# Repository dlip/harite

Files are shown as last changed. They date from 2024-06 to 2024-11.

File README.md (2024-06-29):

# Harite 5-way Switch Keyboard

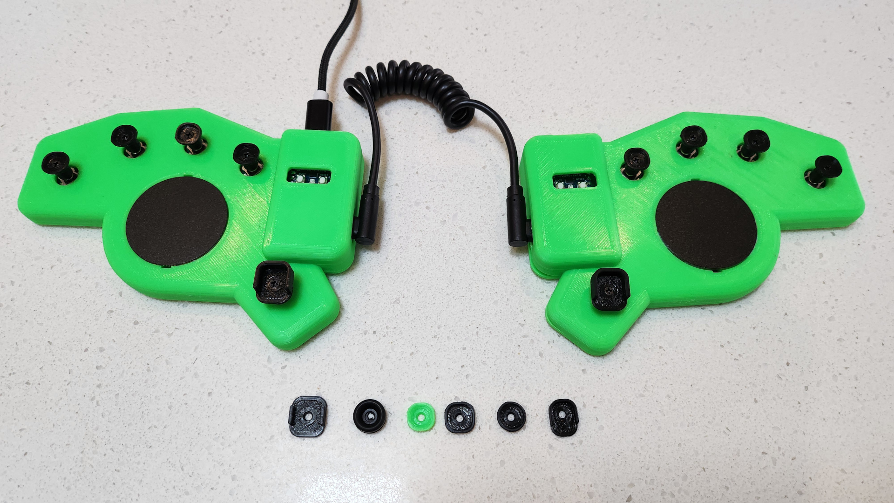
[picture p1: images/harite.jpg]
Harite


- 5-way switches - SKRHADE010 rated at 1,000,000 cycles for each direction
- RP2040-Zero controller
- Split using USB-C to connect the halves
- Dual Cirque 40mm trackpads (optional - you can put a Ploopy or other small trackball in place instead)
- QMK Firmware
- Custom PCB and case
- Hot-swapable joystick caps
- The name comes from the Sumo Slap attack in Japanese
- See a [video demonstration](https://youtu.be/vVsztPqckJc)
- If you would like to make your own, checkout the detailed [build guide](build.md)

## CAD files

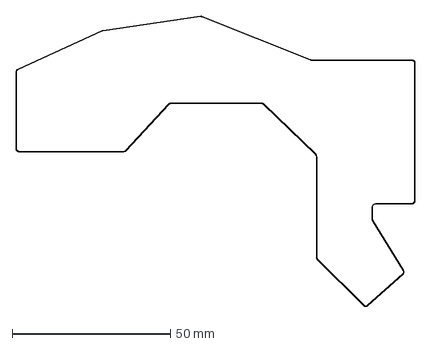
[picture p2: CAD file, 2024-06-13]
design/harite-pcb.dxf
125.9 x 91.7 mm

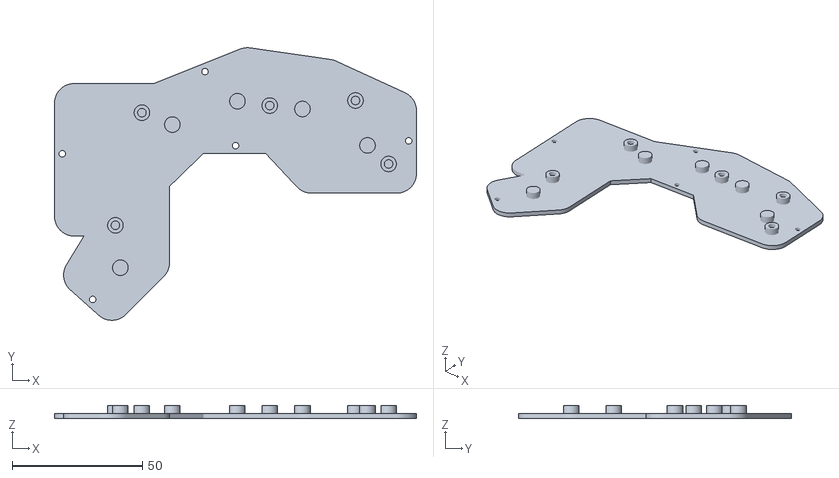
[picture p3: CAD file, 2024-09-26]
printables/Case (no cirque) (untested) - base - right.stl
139.1 x 104.8 x 5.00

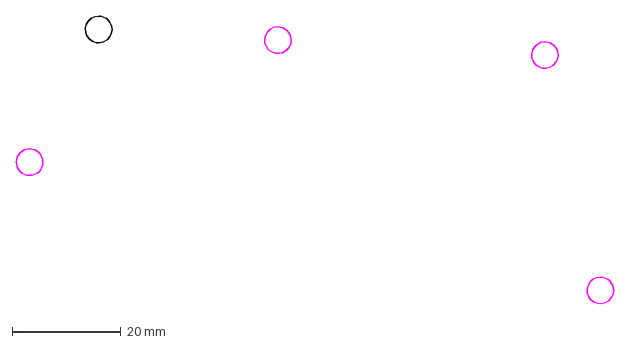
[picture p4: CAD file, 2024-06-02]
design/harite-holes.dxf
109.9 x 53.1 mm

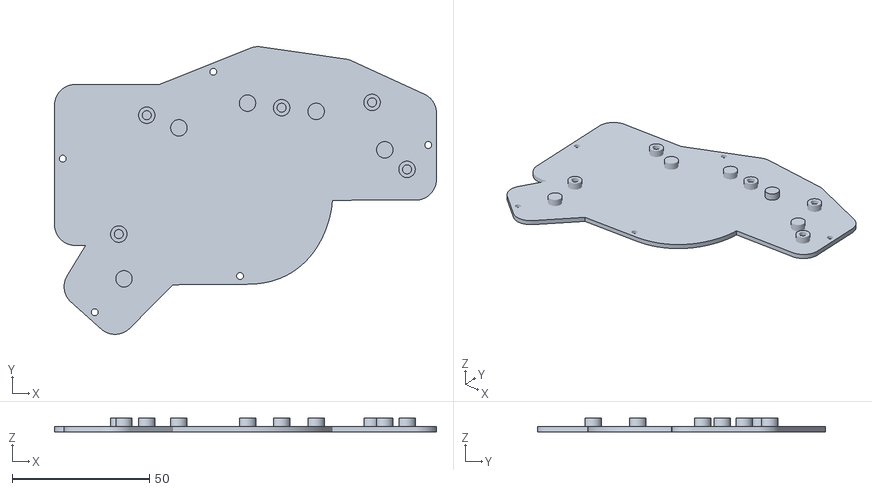
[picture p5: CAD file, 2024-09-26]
printables/Case - base - right.stl
139.1 x 104.8 x 5.00

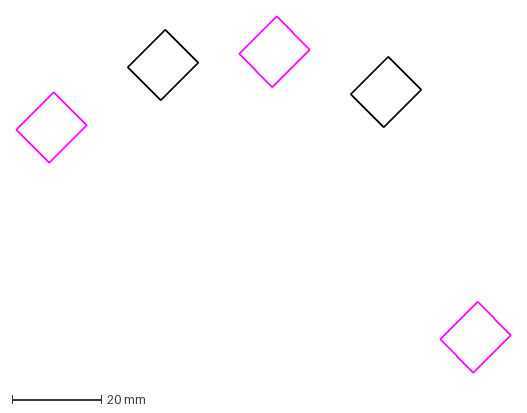
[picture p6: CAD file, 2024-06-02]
design/harite-switch.dxf
110.8 x 79.8 mm

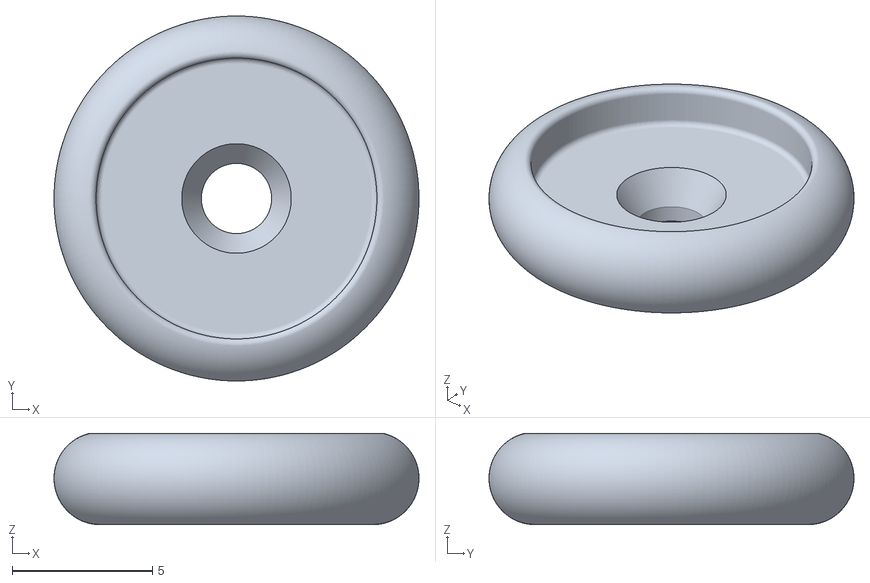
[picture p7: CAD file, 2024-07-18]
printables/Cap - Meta Quest Thumbstick.stl
13.0 x 13.0 x 3.26

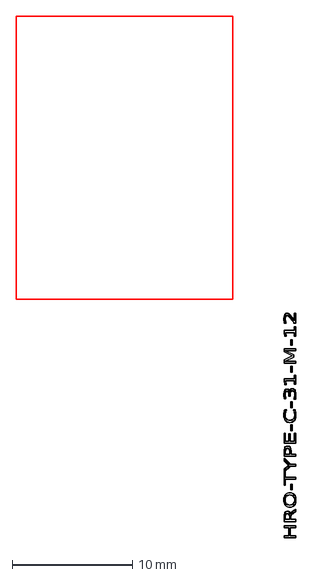
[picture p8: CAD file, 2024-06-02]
design/harite-mcu.dxf
23.3 x 43.3 mm

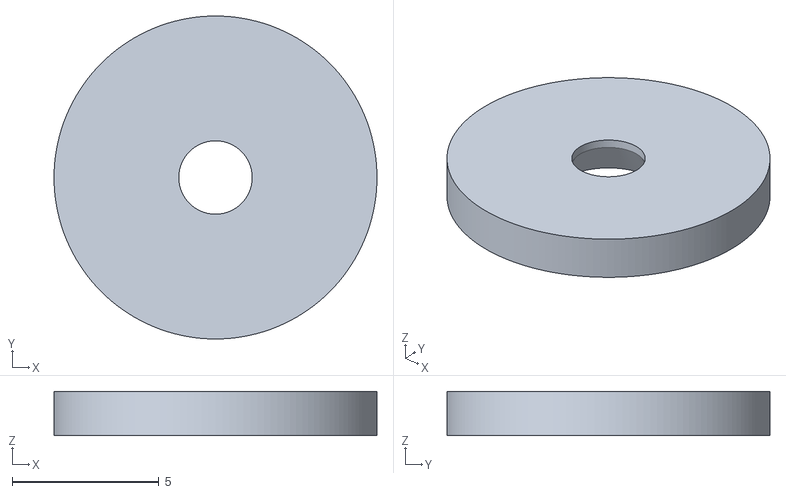
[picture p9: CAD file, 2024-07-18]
printables/Cap - Rubber Feet Pad.stl
11.0 x 11.0 x 1.50

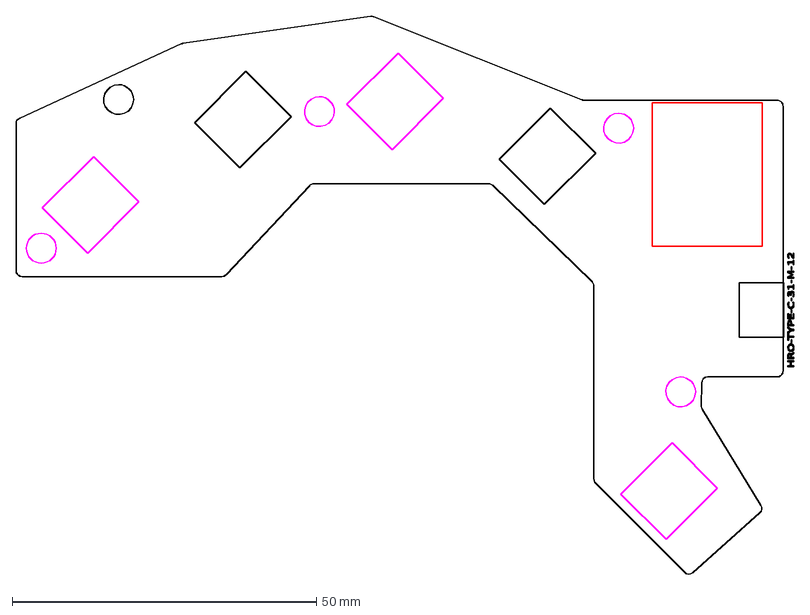
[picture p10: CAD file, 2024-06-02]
design/harite-brd.dxf
127.8 x 91.7 mm

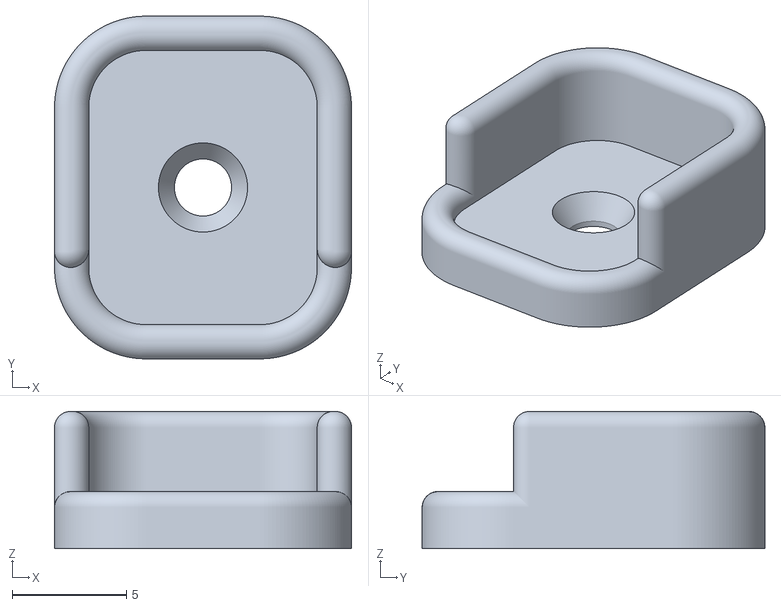
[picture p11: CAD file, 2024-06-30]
printables/Cap - Seat.stl
13.0 x 15.0 x 6.00

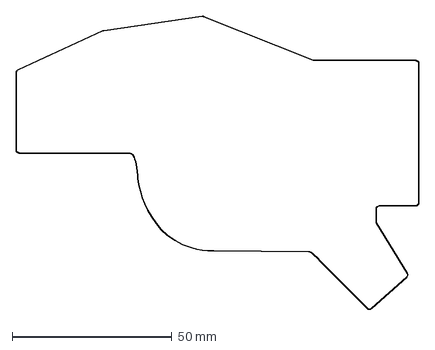
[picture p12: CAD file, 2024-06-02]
design/harite-brd-cirque.dxf
125.9 x 91.7 mm

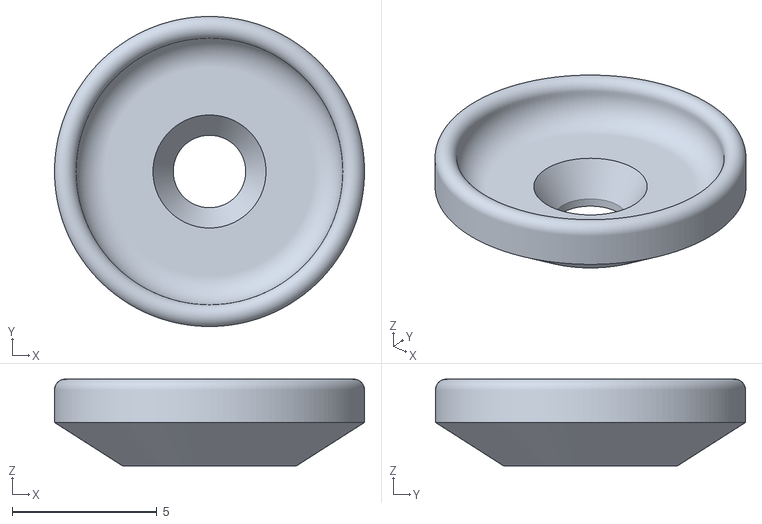
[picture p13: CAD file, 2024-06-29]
printables/Cap - Round.stl
10.7 x 10.7 x 3.00

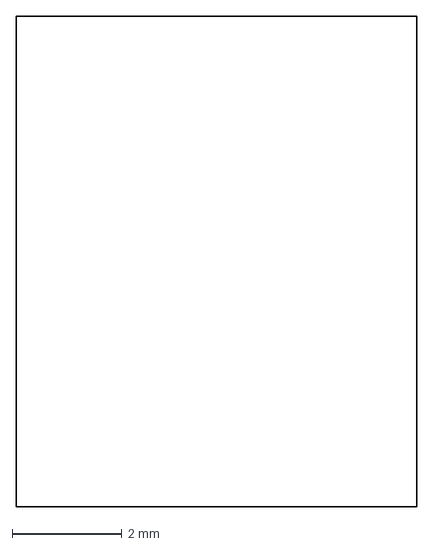
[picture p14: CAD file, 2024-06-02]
design/harite-usb.dxf
7.30 x 8.94 mm

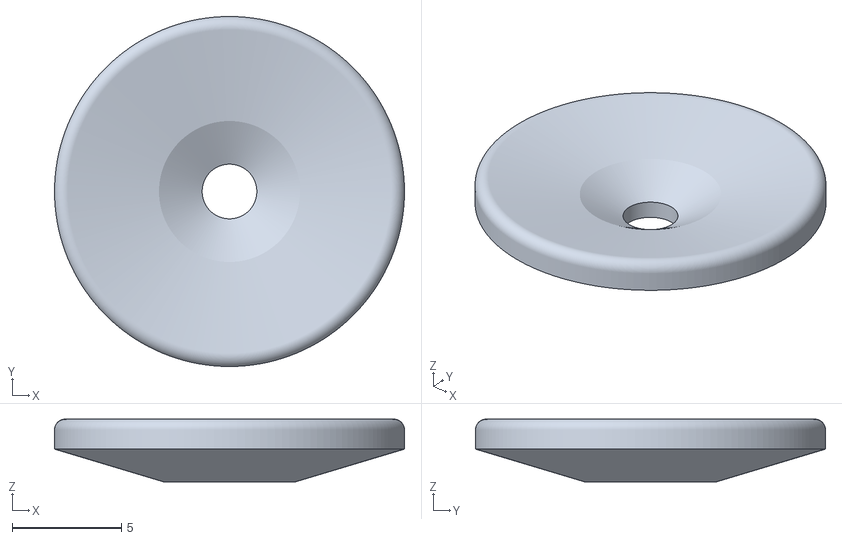
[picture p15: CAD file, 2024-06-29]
printables/Cap - Disc.stl
16.0 x 16.0 x 2.88

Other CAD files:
design/key-cirque-40mm.stl
printables/Cap - Side Guards.stl
printables/Cap - Rounded Square.stl
printables/Stem.stl
printables/Case (no cirque) (untested) - base - left.stl
printables/Case - base - left.stl

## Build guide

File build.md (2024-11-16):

# Harite Build Guide

## Issues and Improvements

For any known issues and improvements please see the repo's [issues](https://github.com/dlip/harite/issues)

## BOM

- Harite PCB - order from your preferred PCB manufacturer using the gerber files in the [gerber_to_order](./gerber_to_order) folder
- 2 x RP2040-Zero controller with headers 2.5mm height
- 2 x Cirque 40mm Trackpads TM040040-2024-302 flat overlay (optional)
  - If you are able to test the no cirque case please let me know if it was successful
- 2 x HRO TYPE-C-31-M-12 USB C female ports
- 10 x SKRHADE010 5-way switches
- 50 x 1N4148 SOD-123 Diodes
- 1 x USB-C to USB-C cable to connect halves
- 1 x USB-C to USB-A/C cable to connect to pc
- 10 x M2 5mm flat head screws for base
- 20 x M2 4mm flat head screws for pcb and hot-swapable joysticks
- 30 x Knurled Insert Nuts M2 x 3mm Length x 3.5mm outer diameter (20 for the case and 10 for the hot-swapable joysticks)
- 6 x insulated wires 6cm approx. to connect cirque trackpad the the PCB. I used some ethernet cable which contiains 8 wires inside and stripped the ends with an Irwin vise-grip
- 3D printed Case and joystick parts - the STLs are in the [printables](./printables) folder. If you want to modify anything, this is the [Onshape Project](https://cad.onshape.com/documents/b93bd8dc5e080887b7a35bc8/w/2fa13694cc5562fc6be45ae5/e/0e302524d10cd22e841a2c15)
- 10 x rubber feet for case base
- Blu-tack or similar to stick down Cirque trackpad
- Super glue for joytick stems
- Soldering tools

## Print Settings

| Part | Layer Height | Supports | Brim |
| --- | --- | --- | ---- |
| Case - top | 0.1mm | yes | no |
| Case - bottom | 0.2mm | no | no |
| Stem/Caps | 0.1mm | no | yes  |

## Steps

### Firmware

It's a good idea to flash both RP2040-Zero to ensure they aren't dead

- Install [QMK CLI](https://github.com/qmk/qmk_cli)
- Git clone my [QMK Firmware](https://github.com/dlip/qmk_firmware/tree/dlip/keyboards/harite)

```
git clone https://github.com/dlip/qmk_firmware.git
cd qmk_firmware
```

- Hold the boot button while connecting the RP2040-Zero and a new drive should appear
- Flash the left

```
qmk flash -kb harite -km default -bl uf2-split-left
```

- Flash the right

```
qmk flash -kb harite -km default -bl uf2-split-right
```

### Soldering USB Port

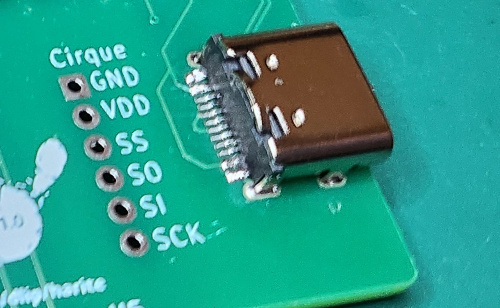
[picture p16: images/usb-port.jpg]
USB Port


- Since its quite challenging, solder on the usb ports on both sides. Watch this [YouTube video on drag soldering](https://www.youtube.com/watch?v=uguPxmkmaSg&t=163s&ab_channel=OffTheClack) for tips.
- Test the connections with a multimeter: set it to continuity mode and ensure you only hear a beep when connecting the following pairs by testing one of the pairs against every other pin.

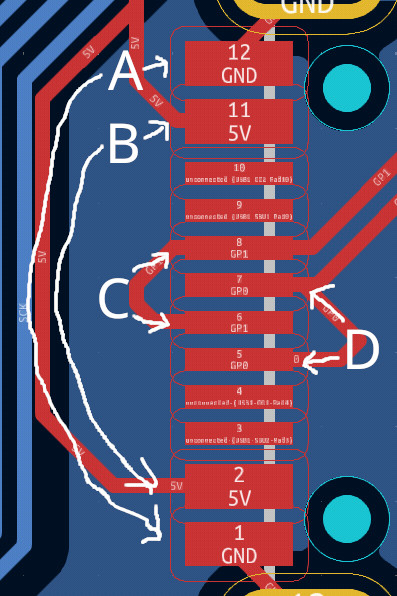
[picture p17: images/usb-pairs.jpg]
USB Pairs


### Soldering RP2040-Zero

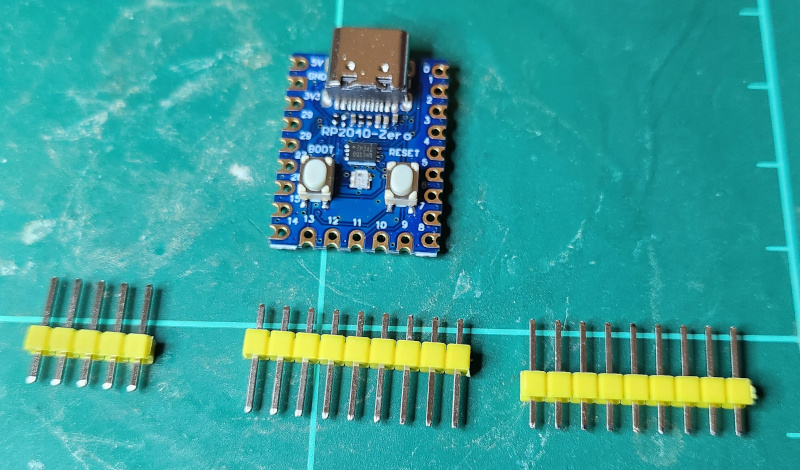
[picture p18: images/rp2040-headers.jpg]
RP2040-Zero with headers


- If the legs on the on the headers are longer than 3mm you will need to cut them shorter.

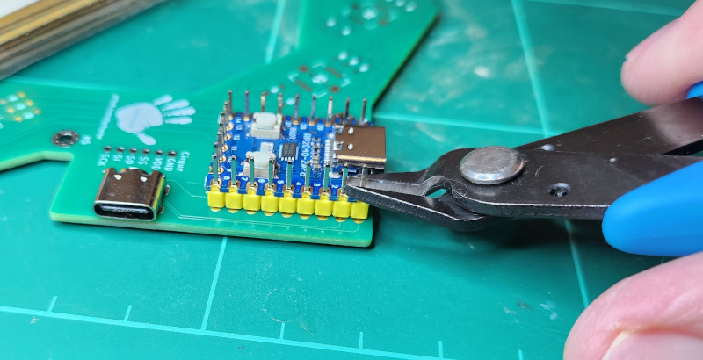
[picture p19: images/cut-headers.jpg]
Cut Headers


- Insert into the top of the pcb and slide RP2040-Zero onto it to ensure the legs are straight. You can use sticky tape on the top to hold it in place.

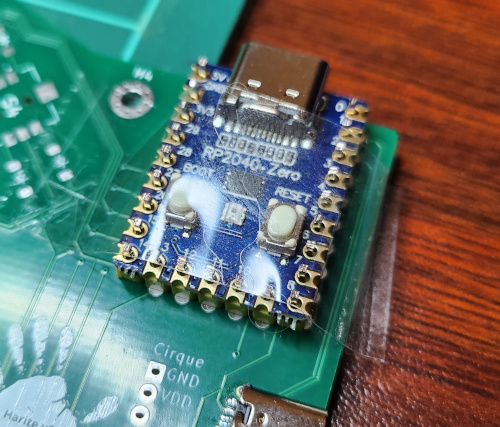
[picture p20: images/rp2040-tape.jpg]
RP2040-Zero Taped


- Flip the board to solder the bottom side, then remove the tape and solder the top side.

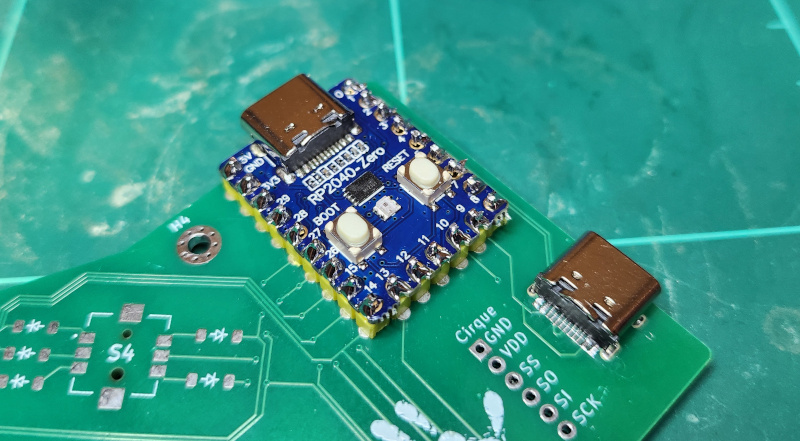
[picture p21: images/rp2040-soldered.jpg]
RP2040-Zero Soldered


### Test Connection Between Halves

- IMPORTANT: You must never connect or disconnect the halves while they are connected to the computer since it may cause a power surge and fry some components.
- Run `qmk console`
- Connect halves via USB-C cable
- Connect either half's RP2040-Zero to the computer
- If you see "Target connected" in the console after a few retries you are good to continue

```
Ψ Console Connected: Dane Lipscombe harite (FEED:0000:1)
Dane Lipscombe:harite:1: Failed to execute slave_matrix
Dane Lipscombe:harite:1: Target disconnected, throttling connection attempts
Dane Lipscombe:harite:1: Failed to execute slave_matrix
Dane Lipscombe:harite:1: Target disconnected, throttling connection attempts
Dane Lipscombe:harite:1: Failed to execute slave_matrix
Dane Lipscombe:harite:1: Target disconnected, throttling connection attempts
Dane Lipscombe:harite:1: Target connected
```

### Soldering 5 Way Switches and Diodes

- Be careful with the switch orientation: the side with the 'v' shape cutout goes at the top, relative to the PCB's switch label (north east for the left side and north west for the right side)

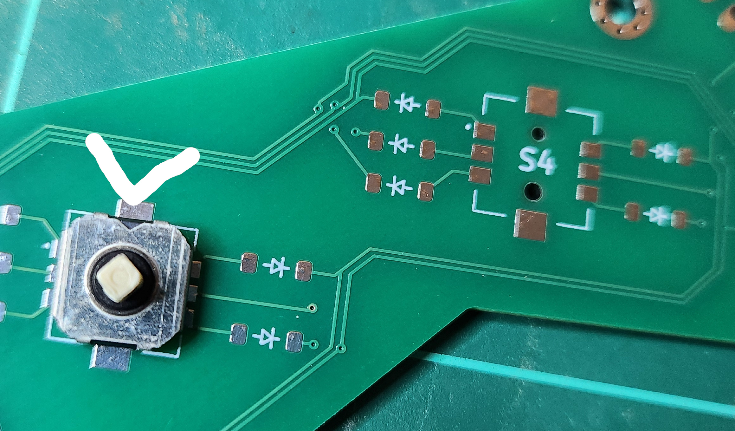
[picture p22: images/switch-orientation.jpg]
Switch Orientation


- Be careful with the diode orientation: the side with the line on the diode goes at the tip of the arrow on the PCB's label

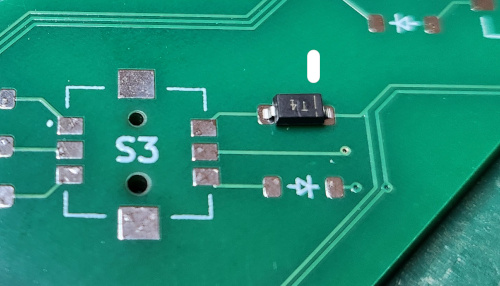
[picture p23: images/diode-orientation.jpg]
Diode Orientation


- Prepare each set of pads by soldering one of its pads

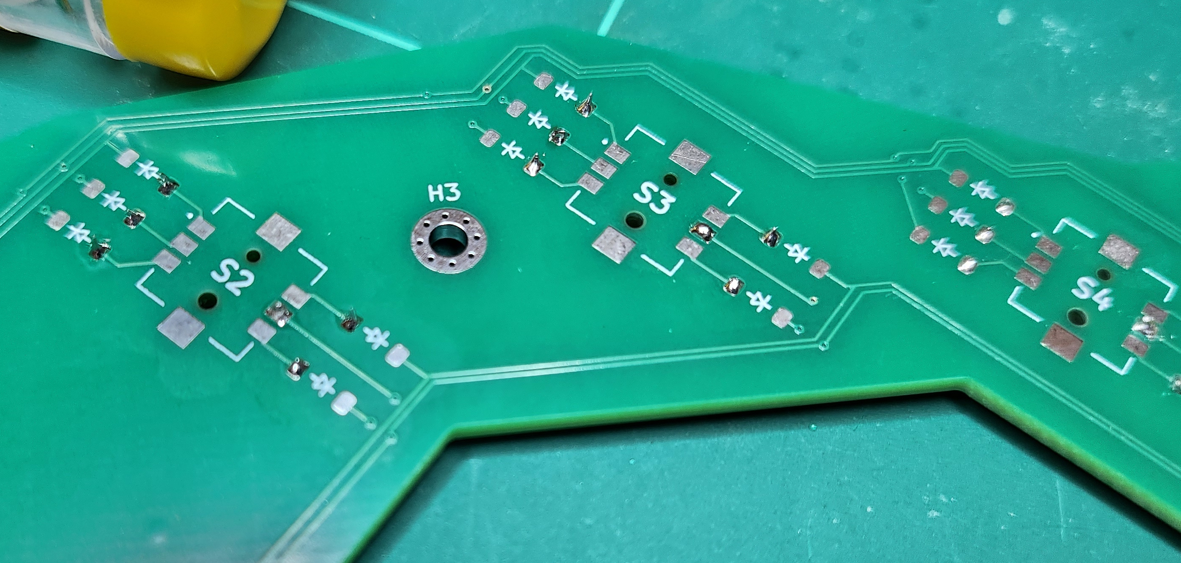
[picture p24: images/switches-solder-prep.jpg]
Switches Solder Prep


- Solder the first pad of each component. Ensure they are all aligned to the other pads then solder the rest of them.

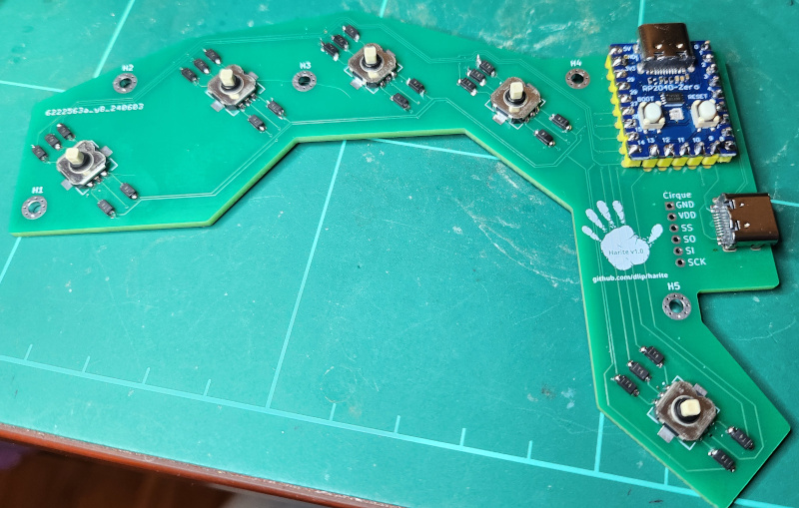
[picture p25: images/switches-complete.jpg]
Switches Complete


- Test the 5 way switches are working by connecting this half to the PC via the RP2040-Zero with the USB cable and pressing each direction then its center switch. You should see these characters typed for each direction: 'u', 'd', 'l', 'r', 'c'

### Soldering Cirque Trackpad

- Note: in my photos I soldered the wires on the front side. I realised afterwards that it might have been easier to do it on the back, so I have added the labels there in the latest design. There should be enough room with the 3mm stand-offs to do it from the back but it would be great if someone could try this and let me know, I would like to make it the preferred method. Photos would be appreciated too!
- Prepare wires and strip one end of each to about 2mm and bending it 90 degrees. Keep the wires a bit longer than needed as we will cut it to length afterwards. It's good to use different coloured wires to help keep track of what goes where.
- Insert wires into the labeled cirque holes and solder on the opposite side

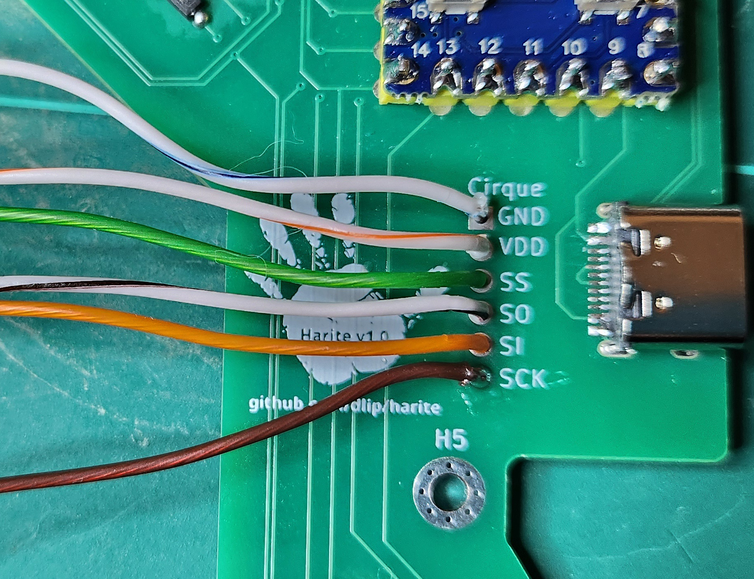
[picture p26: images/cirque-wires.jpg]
Cirque Wires


- The Cirque orientation is different for each side, ensure the 2 cutouts point towards the RP2040-Zero

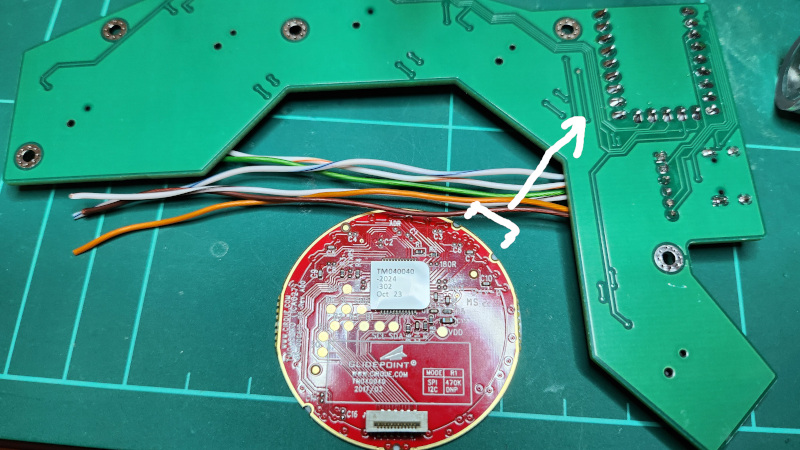
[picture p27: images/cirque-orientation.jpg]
Cirque Orientation


- In order to ensure the wires are the correct length to allow enough slack to fit through the case in the end, I recommend taping it and the PCB to the case while soldering. I messed this part up many times, trust me its worth the effort.

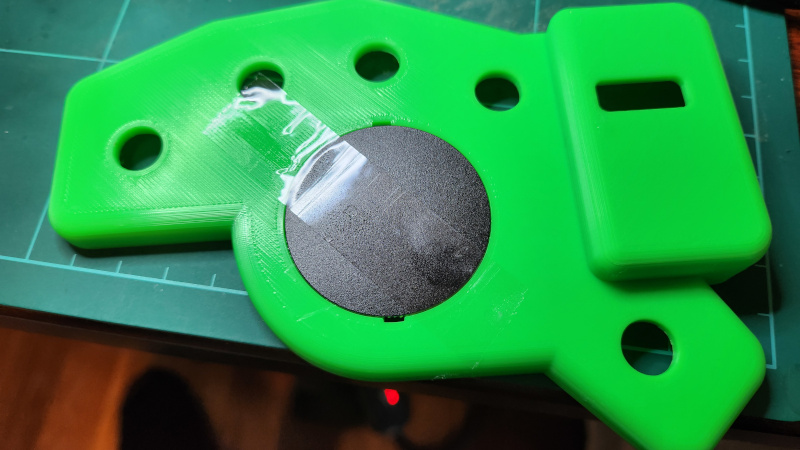
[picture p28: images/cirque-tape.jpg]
Cirque Taped


- Add solder to each of the 6 pads on the Cirque
- Cut each wire to length, ensuring plenty of slack by curving it down then up as in the image
- Strip each end and bend it 90 degrees

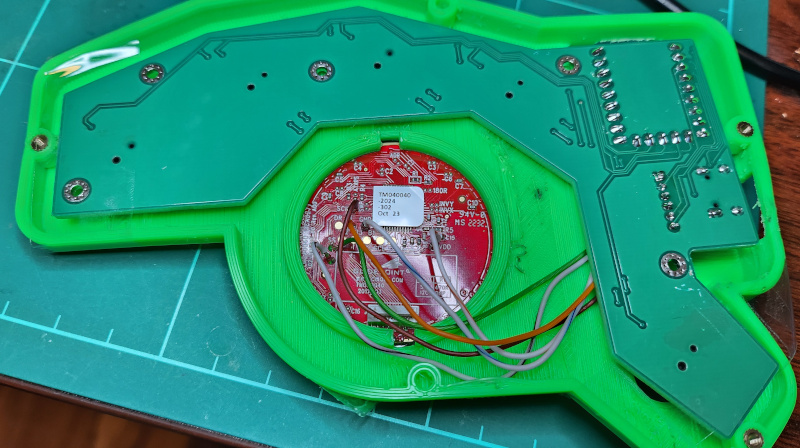
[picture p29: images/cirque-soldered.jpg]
Cirque Soldered


- Connect to the computer and test you can move the cursor
- Remove the tape and carefully push the Cirque through the slit in the case. Try not to bend the the wires connecting to the Cirque, its better to bend at the PCB side since they have a stronger weld

### Case

- Melt knurled insert nuts into holes in the base and top. Heat soldering iron to about 180c temperature and melt while holding the nut down with tweezers to ensure its level

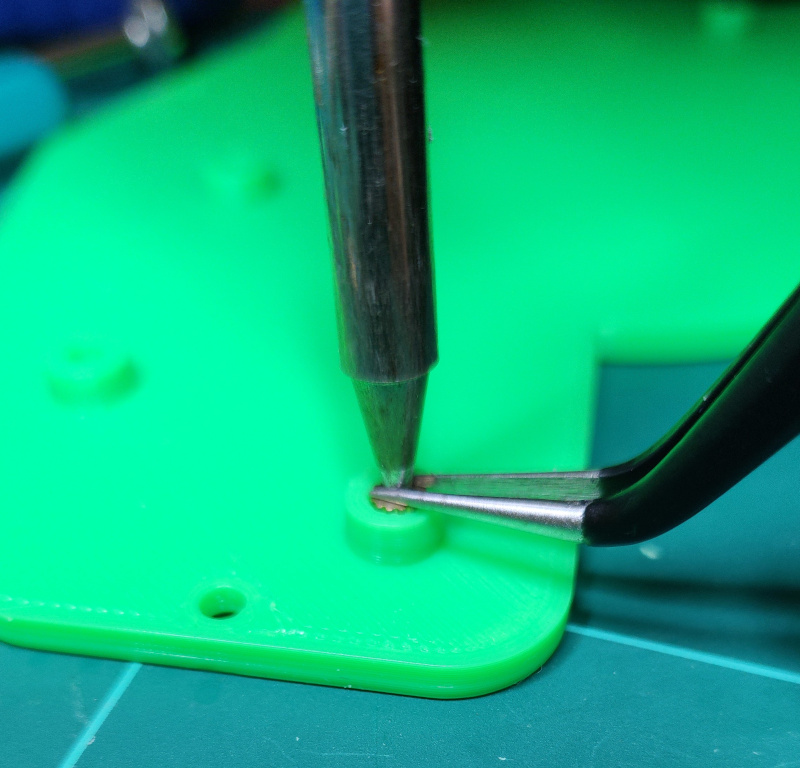
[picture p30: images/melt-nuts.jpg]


- Screw the PCB to the 3D printed base using the M2 4mm screws

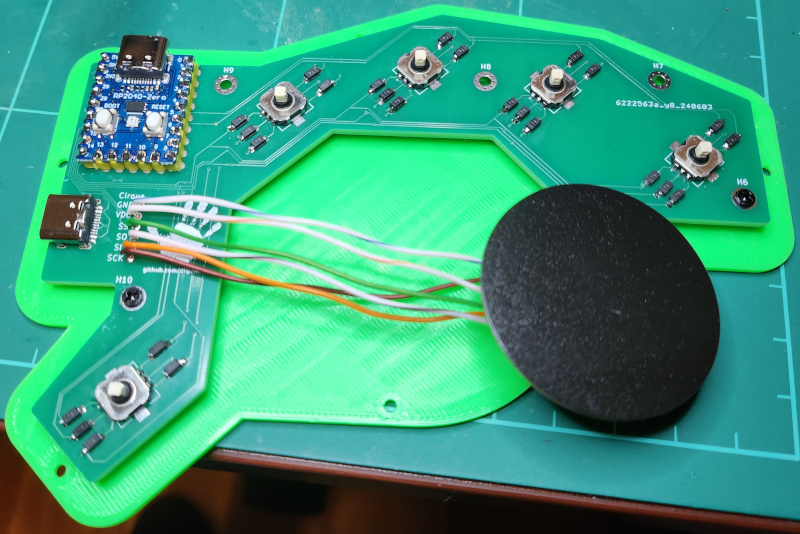
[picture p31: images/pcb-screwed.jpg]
PCB Screwed


- Put the 3D printed top over the top while carefully feeding the Cirque trackpad through the slit and into position, following the 2 notches to ensure it has the correct rotation

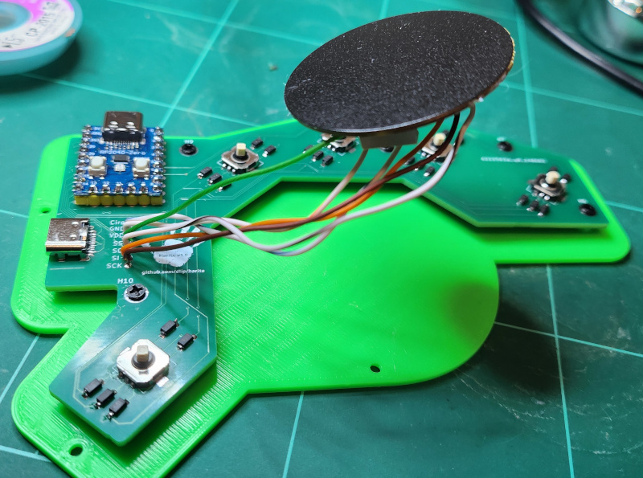
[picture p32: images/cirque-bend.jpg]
Cirque Bend


- Add some Blu-tack or similar to keep it from coming out

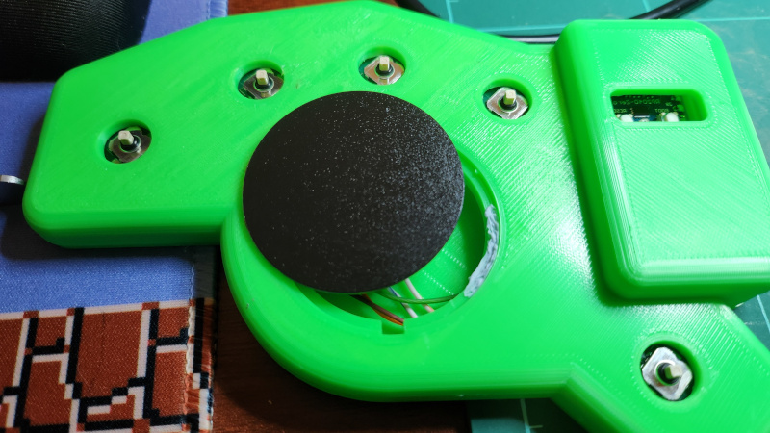
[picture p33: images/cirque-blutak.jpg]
Cirque Blu-tack


- Screw on base using M2 4mm flat head screws
- Add rubber feet

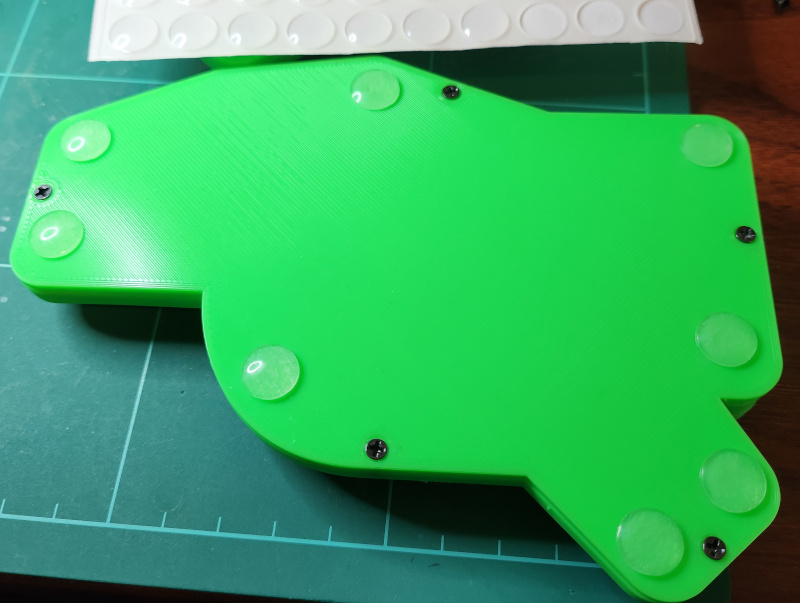
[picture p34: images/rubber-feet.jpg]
Rubber feet


### Joysticks

In order to ensure the top of the case can still be removed, the joysticks have a stem that is separate to the cap which is glued on

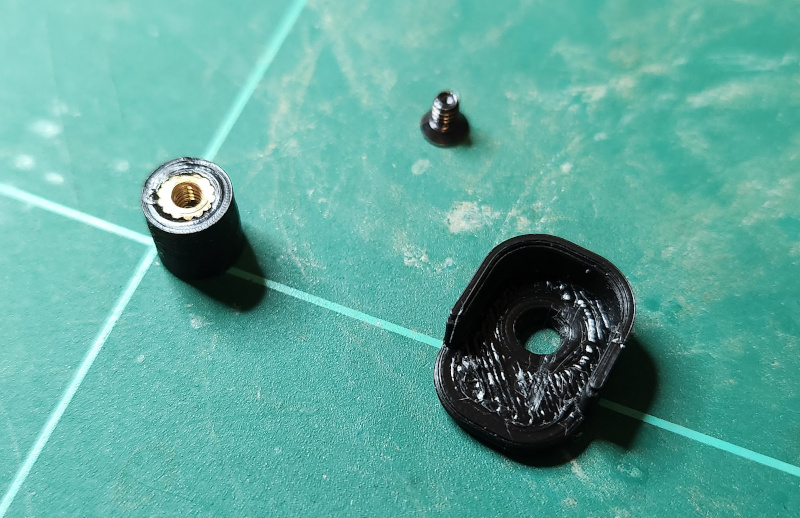
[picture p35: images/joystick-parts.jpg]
Joystick Parts


- Test if the 3D printed stem with the 2mm or 2.1mm hole fits comfortably on the switch stem without too much forcing. If neither are great, you can modify it in OnShape and then export it to stl
- Melt knurled insert nuts into holes in the top of the stem. Do your best to make it flat, and if some melt off to the side its better to discard it and make a new one since they are going to be permananty attached
- Squeeze a small amount of super glue out onto a disposable surface and roll the tip of a toothpick to lightly cover it

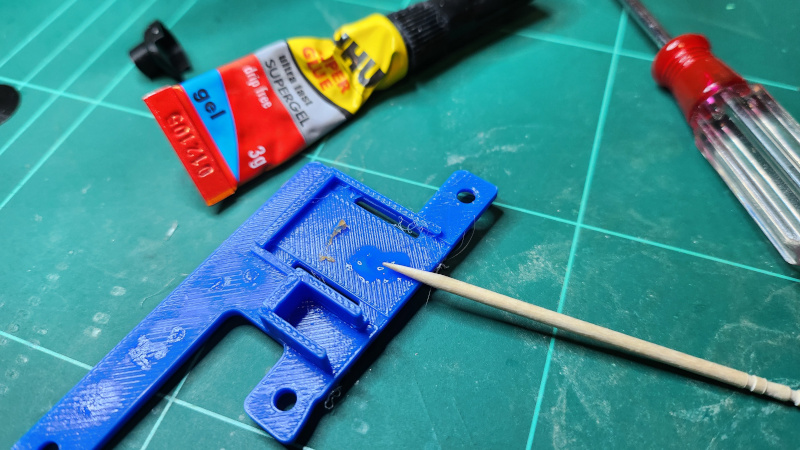
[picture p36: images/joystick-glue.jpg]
Joystick glue


- Thinly coat the inside of the switch hole at the bottom of the stem with super glue

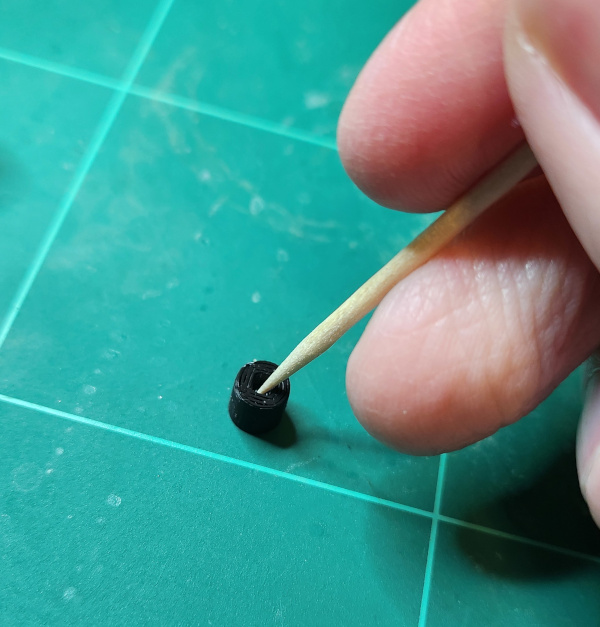
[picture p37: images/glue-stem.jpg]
Glue stem


- Press firmly onto switch and allow to set

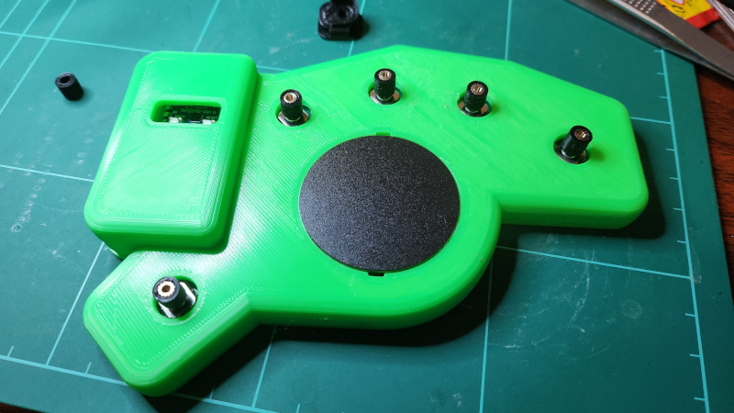
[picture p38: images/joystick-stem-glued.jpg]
Joystick stem glued


- Screw on cap of choice using M2 4mm flat head screws

### Joystick Caps

There are a few different joystick caps in the printables folder

#### Meta Quest Thumbstick

This is my current favourite when combined with some cheap silicone thumbcaps from Ali Express

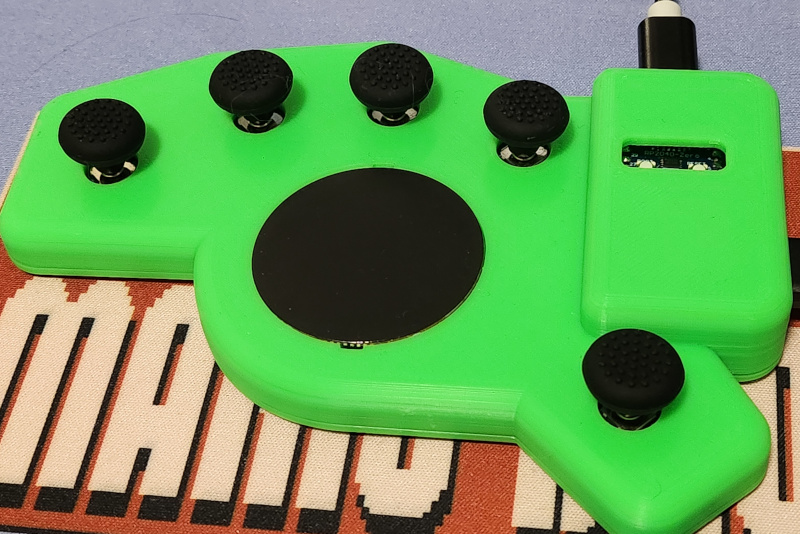
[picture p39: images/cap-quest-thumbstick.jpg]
Cap Quest thumbstick


#### Rubber Feet Pad

This is my next favourite and its easier if you already have some flat rubber feet lying around

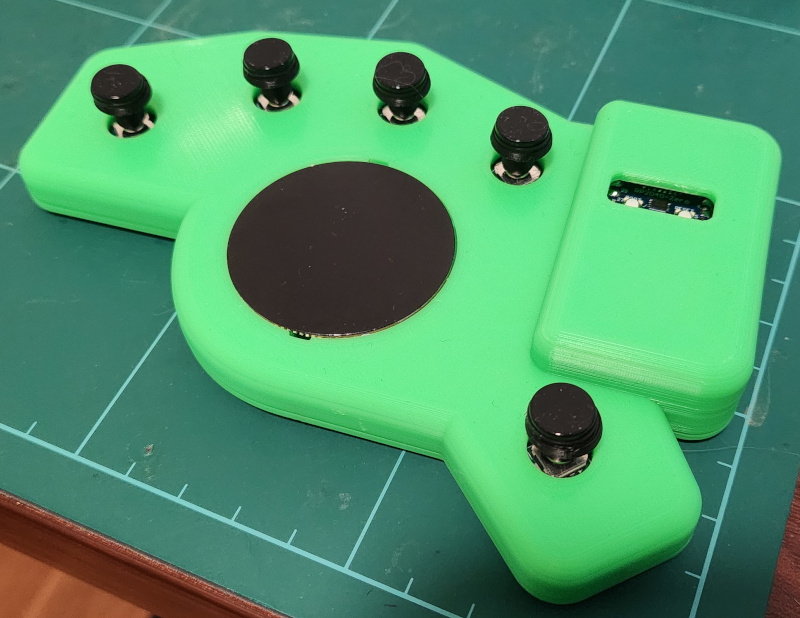
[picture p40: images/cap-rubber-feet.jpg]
Rubber Feet Pad


#### Rounded square / Seat

This was my first 2 designs, the rounded square isn't bad but I really need some rubber grip with my dry hands.

The seat is ok in the left/right directions, but down is a bit uncomfortable and up is hard to feel any feedback from the switch to know if you have pressed it or not.

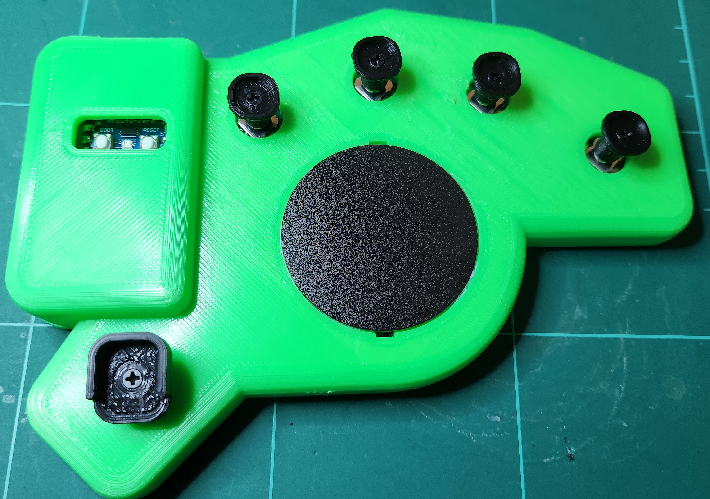
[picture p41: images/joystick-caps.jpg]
Joystick Caps


### Congratulations

- Try my [Stained layout](https://github.com/dlip/qmk_firmware/tree/dlip/keyboards/harite/keymaps/stained) or make your own
- Play [Eye of the tiger](https://www.youtube.com/watch?v=CiIkBT-HFOA&ab_channel=n1ckr1vers) and start your epic training montage!

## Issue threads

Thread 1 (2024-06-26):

More secure and hot swap-able joysticks

dlip, 2024-06-26:
Sometimes the joystick falls off while typing, in particular the thumb stick since there is less downward force and more tilting. They are not glued currently and there is only a small 2mm^2 surface area to fit the stick on to and hope it stays securely in place. I would also like to maintain the ability to remove the top in case is needs to be serviced.

Some options I have considered:

- Glue current joystick on, but increase the hole size so the top could still be removed. This would expose more of the PCB and i might want to improve the shape later on.
- Design a stem that has some sort of locking mechanism so the caps can be screwed on/off, and glue the stem on permanently.
- Holding the stick on with some sort of small screw?

Any other ideas would be appreciated 🙏

dlip, 2024-06-27:
Using the same knurled insert nuts and screws from the case, this is actually working pretty well!

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

dlip, 2024-06-29:
Added to documentation

Closed 2024-06-29.

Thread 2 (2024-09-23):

ordering of case

drlkf, 2024-09-23:
Hey! Thanks for sharing this great project. I have a question that may be stupid because I've never used a 3d printer or ordered 3d printed parts before, but should I order the same case twice for each type and mention to reverse them? Will the printer operator be able to do that with only a single file?

Thanks!

dlip, 2024-09-26:
@drlkf I've added left/right case files

Closed 2024-09-26.

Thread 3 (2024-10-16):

QMK console never detects other half

drlkf, 2024-10-16:
Hi! It's me again :)

I've ordered my parts and started soldering, but I'm having trouble connecting the two parts. I have done the following:

- Soldered each RPI2040 and flashed them with their respective half firmware
- Soldered both USB-C ports to the PCBs and made sure the pin pairs respond according to the guide
- I also checked continuity between the USB-C pins and their connected pin on each RPI, they all respond as expected

But when I start the QMK console, it produces the `slave_matrix` error indefinitely like so:

```
Ψ Console Connected: Dane Lipscombe harite (FEED:0000:1)
Dane Lipscombe:harite:1: Failed to execute slave_matrix
Dane Lipscombe:harite:1: Target disconnected, throttling connection attempts
Dane Lipscombe:harite:1: Failed to execute slave_matrix
Dane Lipscombe:harite:1: Target disconnected, throttling connection attempts
```

I've tried plugging both halves and they produce the same behavior. I don't really know what to check at this point, could it be the USB-C cable that is poor quality? I'm using a cheap 60W cable from AliExpress, tried 2 of them that work find with my phone, should I try a specific brand? If it isn't the cable, could you give any pointers on what to check?

Thank you!

dlip, 2024-10-18:
Hi @drlkf,
I don't think it would be the cable, even cheap ones are decent quality these days. Though you could do a continuity check between the halves. The A, B, C, D pairs should connect to the same ones on the other side and no other pins.

drlkf, 2024-10-26:
Indeed, I found my connectivity issue doing this. Thanks!

Closed 2024-10-26.

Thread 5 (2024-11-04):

Develop Harite Optimized layout

dlip, 2024-11-04:
My basic engram remapping was good for me to easily get to a decent speed very quickly, but its not optimized for this style of keyboard. The pinky key is quite heavy, and having such a common key as 'n' on there is not great. Also it doesn't take advantage of same finger rolls, which feel very nice on harite but would be considered a SFB on a regular layout.

dlip, 2024-11-04:
I discovered [this post](https://mbuffett.com/posts/optimizing-datahand-layout/) about creating a layout for the sval board, which has a lot of similarities to harite and have created my [own fork](https://github.com/dlip/keyboard_layout_optimizer) of the layout optimizer to give it a try

dlip, 2024-11-16:
I created a fork of keyboard layout optimizer https://github.com/dlip/keyboard_layout_optimizer and have designed some new metrics for use with "directional keyboards"

The stained layout is geared towards rolls and mainly using the index, middle and ring fingers, and being very rolley,  but using the following metrics you can generate layouts suited to your tastes.

Bigram Metrics
Same Finger Scissors: Going North to South or East to west on the same finger
Directional Change: Changing direction on different fingers on the same hand

Trigram Metrics
Unidirectional Rolls: Rolling from one finger to the next in the same direction on one hand, then pressing any key on the other hand
Unidirectional Onehands: Rolling from one finger to the next, to the next in the same direction on one hand

```
          LEFT HAND                         RIGHT HAND

  Pinky   Ring    Middle  Index     Index   Middle  Ring    Pinky

    q       f       w       o         l       u       b       z
  \   '   x   k   y   h   m   c     i   g   r   v   p   j   ;   /
    ,       s       t       a         n       e       d       .

Unigram metrics:
  Not found: 0.2689% of 1.0000
    96.51 Finger Balance                      | Finger loads % (no thumb): 1.6 9.5 17.3 21.0 - 20.0 21.7 7.4 1.4
     0.33 Hand Disbalance                     | Hand loads % (no thumb): 49.45 - 50.55
   274.67 Key Costs                           | Worst unigrams: i (10.33%), r ( 8.78%), s ( 6.99%)

Bigram metrics:
  Not found: 0.4501% of 1.0000
     4.67 Same Finger Scissors                | Worst: ig (28.41%), gi (15.29%), ue (13.71%);  Worst non-fixed: ig (28.41%), gi (15.29%), ue (13.71%)
    65.90 Directional Change                  | Worst: to ( 7.17%), ha ( 5.86%), le ( 5.17%);  Worst non-fixed: to ( 7.17%), ha ( 5.86%), le ( 5.17%)

Trigram metrics:
  Not found: 0.8231% of 1.0000
   -26.09 Unidirectional Rolls                | Worst: and ( 6.59%), ent ( 4.58%), for ( 4.42%);  Worst non-fixed: and ( 6.59%), ent ( 4.58%), for ( 4.42%)
    -3.09 Unidirectional Onehands             | Worst: sta (38.07%), den (15.36%), pri (13.72%);  Worst non-fixed: sta (38.07%), den (15.36%), pri (13.72%)
   -71.14 Same Finger Rolls                   | Worst: the (13.70%), her ( 2.38%), ter ( 2.14%);  Worst non-fixed: the (13.70%), her ( 2.38%), ter ( 2.14%)
   -19.55 Same Finger Onehands                | Worst: ing (52.57%), ver (13.64%), com (10.03%);  Worst non-fixed: ing (52.57%), ver (13.64%), com (10.03%)
    69.13 Alternates                          | Worst: tio ( 3.84%), his ( 2.38%), out ( 1.79%);  Worst non-fixed: tio ( 3.84%), his ( 2.38%), out ( 1.79%)
    34.24 Alternates (sfs)                    | Worst: ion ( 9.70%), wit ( 4.83%), ear ( 3.45%);  Worst non-fixed: ion ( 9.70%), wit ( 4.83%), ear ( 3.45%)

Cost: 425.57 (optimization score: 234978)
```

QMK firmware here https://github.com/dlip/qmk_firmware/tree/dlip/keyboards/harite/keymaps/stained

dlip, 2024-11-16:
@drlkf this might be interesting to you

Closed 2024-11-16.

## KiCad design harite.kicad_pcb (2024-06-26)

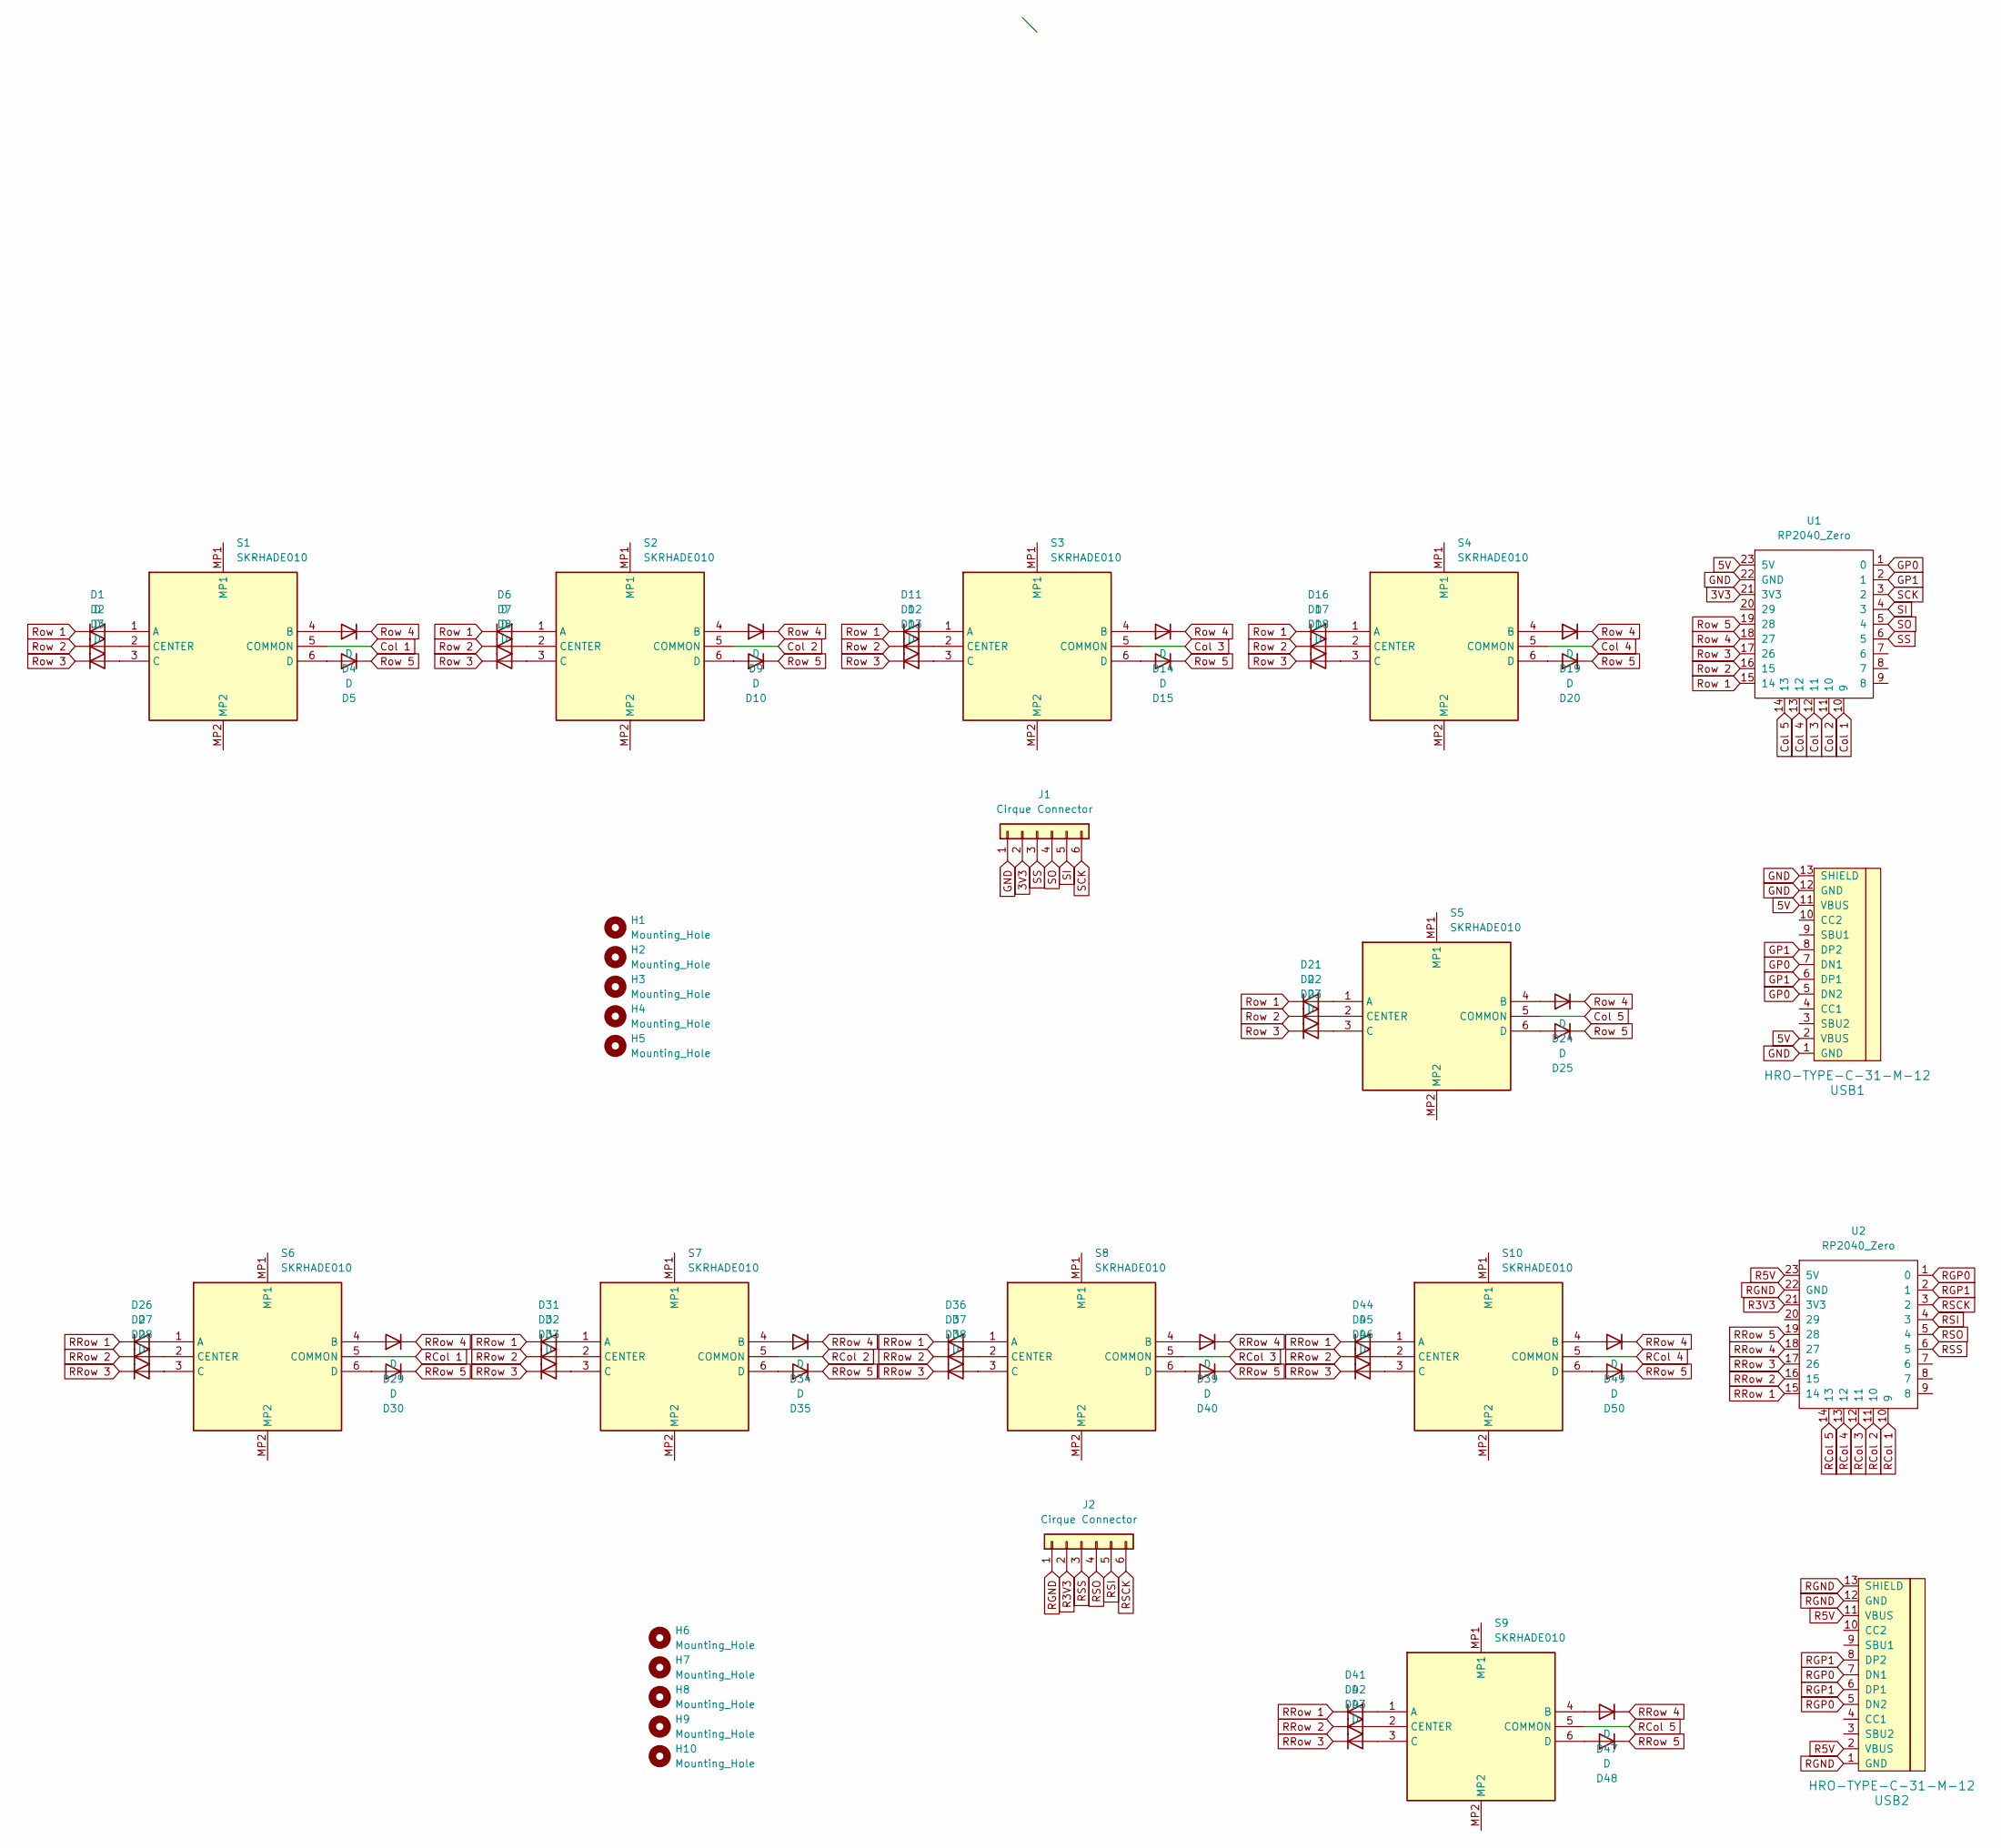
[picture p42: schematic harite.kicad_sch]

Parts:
D1, D2, D3, D4, D5, D6, D7, D8, D9, D10, D11, D12, D13, D14, D15, D16, D17, D18, D19, D20, D21, D22, D23, D24, D25, D26, D27, D28, D29, D30, D31, D32, D33, D34, D35, D36, D37, D38, D39, D40, D41, D42, D43, D44, D45, D46, D47, D48, D49, D50: D; Diode_SOD-123
H1, H2, H3, H4, H5, H6, H7, H8, H9, H10: Mounting_Hole; MountingHole_2.2mm_M2_Pad_Via
J1, J2: Cirque Connector; Cirque-connector
S1, S2, S3, S4, S5, S6, S7, S8, S9, S10: SKRHADE010; SKRHADE; Manufacturer_Part_Number SKRHADE010; Mouser Part Number 688-SKRHAD
U1, U2: RP2040_Zero
USB1, USB2: HRO-TYPE-C-31-M-12

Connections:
3V3: J1.2, U1.21 (3V3)
5V: U1.23 (5V), USB1.2 (VBUS), USB1.11 (VBUS)
Col 1: S1.5 (COMMON), U1.10 (9)
Col 2: S2.5 (COMMON), U1.11 (10)
Col 3: S3.5 (COMMON), U1.12 (11)
Col 4: S4.5 (COMMON), U1.13 (12)
Col 5: S5.5 (COMMON), U1.14 (13)
GND: J1.1, U1.22 (GND), USB1.1 (GND), USB1.12 (GND), USB1.13 (SHIELD)
GP0: U1.1 (0), USB1.5 (DN2), USB1.7 (DN1)
GP1: U1.2 (1), USB1.6 (DP1), USB1.8 (DP2)
unnamed: D1.2 (A), S1.1 (A)
unnamed: D2.2 (A), S1.2 (CENTER)
unnamed: D3.2 (A), S1.3 (C)
unnamed: D4.2 (A), S1.4 (B)
unnamed: D5.2 (A), S1.6 (D)
unnamed: D6.2 (A), S2.1 (A)
unnamed: D7.2 (A), S2.2 (CENTER)
unnamed: D8.2 (A), S2.3 (C)
unnamed: D9.2 (A), S2.4 (B)
unnamed: D10.2 (A), S2.6 (D)
unnamed: D11.2 (A), S3.1 (A)
unnamed: D12.2 (A), S3.2 (CENTER)
unnamed: D13.2 (A), S3.3 (C)
unnamed: D14.2 (A), S3.4 (B)
unnamed: D15.2 (A), S3.6 (D)
unnamed: D16.2 (A), S4.1 (A)
unnamed: D17.2 (A), S4.2 (CENTER)
unnamed: D18.2 (A), S4.3 (C)
unnamed: D19.2 (A), S4.4 (B)
unnamed: D20.2 (A), S4.6 (D)
unnamed: D21.2 (A), S5.1 (A)
unnamed: D22.2 (A), S5.2 (CENTER)
unnamed: D23.2 (A), S5.3 (C)
unnamed: D24.2 (A), S5.4 (B)
unnamed: D25.2 (A), S5.6 (D)
unnamed: D26.2 (A), S6.1 (A)
unnamed: D27.2 (A), S6.2 (CENTER)
unnamed: D28.2 (A), S6.3 (C)
unnamed: D29.2 (A), S6.4 (B)
unnamed: D30.2 (A), S6.6 (D)
unnamed: D31.2 (A), S7.1 (A)
unnamed: D32.2 (A), S7.2 (CENTER)
unnamed: D33.2 (A), S7.3 (C)
unnamed: D34.2 (A), S7.4 (B)
unnamed: D35.2 (A), S7.6 (D)
unnamed: D36.2 (A), S8.1 (A)
unnamed: D37.2 (A), S8.2 (CENTER)
unnamed: D38.2 (A), S8.3 (C)
unnamed: D39.2 (A), S8.4 (B)
unnamed: D40.2 (A), S8.6 (D)
unnamed: D41.2 (A), S9.1 (A)
unnamed: D42.2 (A), S9.2 (CENTER)
unnamed: D43.2 (A), S9.3 (C)
unnamed: D44.2 (A), S10.1 (A)
unnamed: D45.2 (A), S10.2 (CENTER)
unnamed: D46.2 (A), S10.3 (C)
unnamed: D47.2 (A), S9.4 (B)
unnamed: D48.2 (A), S9.6 (D)
unnamed: D49.2 (A), S10.4 (B)
unnamed: D50.2 (A), S10.6 (D)
R3V3: J2.2, U2.21 (3V3)
R5V: U2.23 (5V), USB2.2 (VBUS), USB2.11 (VBUS)
RCol 1: S6.5 (COMMON), U2.10 (9)
RCol 2: S7.5 (COMMON), U2.11 (10)
RCol 3: S8.5 (COMMON), U2.12 (11)
RCol 4: S10.5 (COMMON), U2.13 (12)
RCol 5: S9.5 (COMMON), U2.14 (13)
RGND: J2.1, U2.22 (GND), USB2.1 (GND), USB2.12 (GND), USB2.13 (SHIELD)
RGP0: U2.1 (0), USB2.5 (DN2), USB2.7 (DN1)
RGP1: U2.2 (1), USB2.6 (DP1), USB2.8 (DP2)
RRow 1: D26.1 (K), D31.1 (K), D36.1 (K), D41.1 (K), D44.1 (K), U2.15 (14)
RRow 2: D27.1 (K), D32.1 (K), D37.1 (K), D42.1 (K), D45.1 (K), U2.16 (15)
RRow 3: D28.1 (K), D33.1 (K), D38.1 (K), D43.1 (K), D46.1 (K), U2.17 (26)
RRow 4: D29.1 (K), D34.1 (K), D39.1 (K), D47.1 (K), D49.1 (K), U2.18 (27)
RRow 5: D30.1 (K), D35.1 (K), D40.1 (K), D48.1 (K), D50.1 (K), U2.19 (28)
RSCK: J2.6, U2.3 (2)
RSI: J2.5, U2.4 (3)
RSO: J2.4, U2.5 (4)
RSS: J2.3, U2.6 (5)
Row 1: D1.1 (K), D6.1 (K), D11.1 (K), D16.1 (K), D21.1 (K), U1.15 (14)
Row 2: D2.1 (K), D7.1 (K), D12.1 (K), D17.1 (K), D22.1 (K), U1.16 (15)
Row 3: D3.1 (K), D8.1 (K), D13.1 (K), D18.1 (K), D23.1 (K), U1.17 (26)
Row 4: D4.1 (K), D9.1 (K), D14.1 (K), D19.1 (K), D24.1 (K), U1.18 (27)
Row 5: D5.1 (K), D10.1 (K), D15.1 (K), D20.1 (K), D25.1 (K), U1.19 (28)
SCK: J1.6, U1.3 (2)
SI: J1.5, U1.4 (3)
SO: J1.4, U1.5 (4)
SS: J1.3, U1.6 (5)

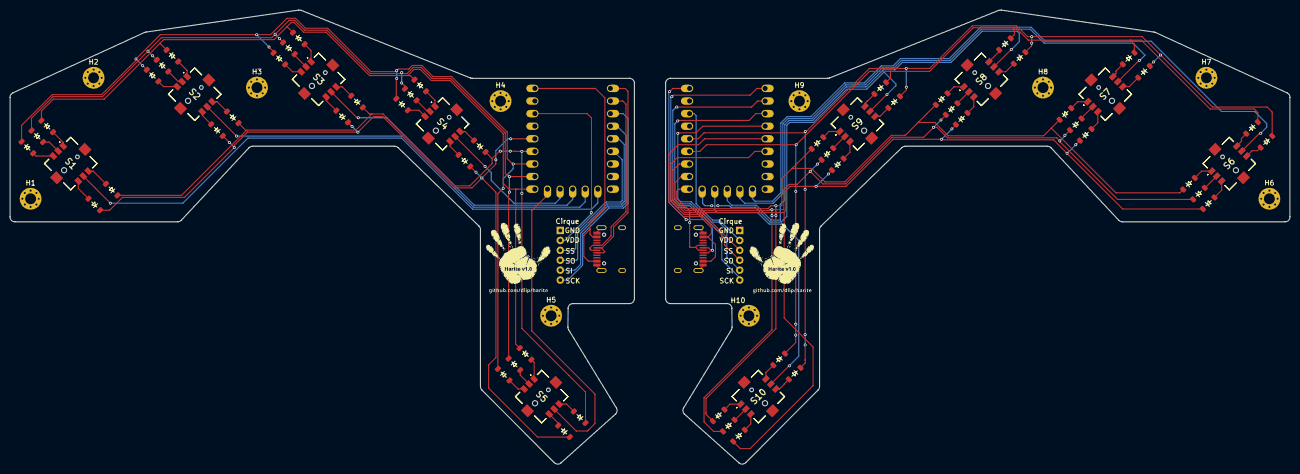
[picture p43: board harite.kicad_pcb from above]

Board: 2 copper layers, 258.2 x 91.6 mm, 76 parts (0 on the bottom side), 88 nets.

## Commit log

2024-05-25 Add kicad project
    [harite.kicad_pcb, harite.kicad_sch]
2024-05-25 Start schematic
    [harite.kicad_pcb, harite.kicad_sch]
2024-05-25 Layout switches
    [harite.kicad_pcb, harite.kicad_sch]
2024-05-26 Add scottokeebs
    [harite.kicad_pcb, harite.kicad_sch]
2024-05-26 Add trrs
    [harite.kicad_pcb, harite.kicad_sch]
2024-05-28 Add usbc and cirque
    [harite.kicad_sch]
2024-05-28 update usbc
    [harite.kicad_pcb, harite.kicad_sch]
2024-05-28 Fix usb
    [harite.kicad_pcb, harite.kicad_sch]
2024-05-28 Add cirque connector
    [harite.kicad_pcb, harite.kicad_sch]
2024-05-29 Update refs
    [harite.kicad_pcb]
2024-05-29 mounting holes
    [harite.kicad_pcb, harite.kicad_sch]
2024-05-29 Use skrhade switch model
    [harite.kicad_pcb, harite.kicad_sch]
2024-05-30 Start case
2024-05-30 export board
    [harite-pcb.dxf]
2024-06-02 Add case files
    [harite-brd-cirque.dxf, harite-brd.dxf, harite-holes.dxf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]
2024-06-02 Mirror sides
    [harite.kicad_pcb, harite.kicad_sch]
2024-06-02 Organise diodes
    [harite.kicad_pcb]
2024-06-02 Connect diodes
    [harite.kicad_pcb]
2024-06-02 Connect the rest
    [harite.kicad_pcb]
2024-06-02 Fix ground
    [harite.kicad_pcb]
2024-06-02 Fix diodes
    [harite.kicad_pcb]
2024-06-02 Track cleanup
    [harite.kicad_pcb]
2024-06-02 Add gerbers
2024-06-03 Add logo
    [harite.kicad_pcb]
2024-06-03 Move cirque labels
    [harite.kicad_pcb]
2024-06-03 Resize logo
    [harite.kicad_pcb]
2024-06-03 Move diode
    [harite.kicad_pcb]
2024-06-03 Regen gerbers
2024-06-25 Add printables
    [Case - base.stl, Joystick - Fingers.stl, Joystick - Thumb.stl]
2024-06-26 Update base
    [Case - base.stl]
2024-06-26 move design
    [harite-brd-cirque.dxf, harite-brd.dxf, harite-holes.dxf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]
2024-06-26 Add Cirque labels to the back
    [harite.kicad_pcb]
2024-06-26 Add no cirque case
    [Case (no cirque) (untested) - base.stl]
2024-06-28 Add hotswap joysticks
    [Joystick - Fingers.stl, Joystick - Stem.stl, Joystick - Thumb.stl]
2024-06-29 Add extra caps
    [Cap - Disc.stl, Cap - Round.stl, Cap - Rounded Square.stl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]
2024-06-29 Add print settings
2024-06-30 Improve seat cap
    [Cap - Seat.stl]
2024-09-26 Add left/right case files
    [Case (no cirque) (untested) - base - left.stl, Case (no cirque) (untested) - base - right.stl, Case - base - left.stl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]
2024-11-17 Add CC2 Cap
    [Cap - CC2.stl]
2024-11-24 Revert "Add CC2 Cap"
    This reverts commit 0095e71b417e125be702f3604542a93561a7ed3b.
    [Cap - CC2.stl]
